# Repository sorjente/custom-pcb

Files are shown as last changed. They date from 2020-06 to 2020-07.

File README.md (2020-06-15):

# Custom STM32L4 PCB

## What?

This is an attempt to build a minimal, custom PCB featuring an STM32L4 MCU, using (ideally only) open source tools.
It will hopefully serve as a stepping stone to build more complex embedded systems.

## Why?

Because learning is fun.

## Who?

[@ayoubsabri](https://ayoubsabri.github.io/) & [@kokkonisd](https://kokkonisd.github.io/).

---

## Setting up this project

To set up this project, you can start by cloning it:

```
$ git clone https://github.com/kokkonisd/custom-pcb
```

You then need to pull `libopencm3`. You can do this by running `make` in `hello_opencm3/`, or do it manually:

```
$ git submodule init
$ git submodule update
$ cd hello_opencm3/libopencm3/ && make
```

You only need to do this once.

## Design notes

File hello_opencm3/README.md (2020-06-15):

# hello_opencm3

This is a simple blinky program whose aim is to test out minimal opencm3 code as well as a custom linker script/startup
program pair.

## Linker script (linker_stm32l452.ld)

This is the script that's fed to the linker and that maps code and data sections to the FLASH and RAM memories on the
MCU. There are some sections we need to account for:

1. `.text`: this entire area goes into the FLASH memory, and can only be read or executed.
    1. `.isr_vector`: the vector table which is essential to the MCU's startup. It's defined in the startup file, and
       its spec can be found on the [STM32L4 Reference Manual][1].
        We need to wrap it with `KEEP()` because it's not explicitly referenced anywhere else in the program, but it
        must be kept and stored at the start of the FLASH memory.
    2. `.text`: the program instructions for our firmware.
    3. `.rodata`: constants of our firmware (if any).
2. `.data`: the non-constant global variables of our firmware, which need to be stored in the FLASH memory but also
            need to be copied to the RAM during reset (see the [startup file](#startup-file-startup_stm32l452c))
3. `.bss`: the zero-initialized global variables of our firmware, which need to be stored in RAM (their values don't
           need to be "remembered" by the FLASH).

## Startup file (startup_stm32l452.c)

This file contains the vector table for the interrupts, as well as the definition of the `Default_Handler` (which just
hangs in case it's called) and the `Reset_Handler`.

The `Reset_Handler` does 3 things:

1. Copies the `.data` section from the FLASH to the RAM
2. Initializes the `.bss` section in RAM to `0`
3. Calls `main()`

This function is called at each reset, as its name implies, and it's essential in order for the firmware to work as
intended.

## Blinky program (src/main.c)

The main firmware of this example is just a simple blinky program, whose aim is to toggle a LED on and off at a certain
frequency. In the NUCLEO-L452RE-P board used for this example, the LED we want to toggle is found on the pin `PB13`.

Before toggling the LED, the clock (and also the FLASH memory) need to be configured. The aim is to have the clock run
at its maximum frequency (80 MHz), so as per the documentation ([RM0394, section 3.3.3][2]) the FLASH's wait states need to be set at 4. Since we're configuring the
FLASH, we can also enable prefetch and instruction/data cache, in order to get the maximum performance.

Concerning the clock, the easiest solution to achieve maximum speed is to use the internal oscillator (HSI), which runs
at 16 MHz. As explained in the documentation ([DS11912, section 3.11, fig. 4][3]), we need to use the main PLL in order to ramp up the speed to 80 MHz. This PLL produces a main output
clock whose frequency is given by the following formula:

```
PLLCLK = PLL_in / M * N / R
```

`PLL_in` is the input fed to the PLL (HSI in our case). Since `R` needs to be equal to at least 2 (the configurations
to choose from are 2, 4, 6 and 8) we need `16 / M * N = 160`. If we set `M = 4` and `N = 40`, this condition is
satisfied, and thus a 80 MHz clock is produced.

It should be noted that the PLL has two more outputs, one for powering USB, RNG and SDMMC, and one for powering SAI. 
Since we are not using these peripherals, we can deactivate these clocks by setting their dividers (equivalents of `R`
in the case of `PLLCLK`) to `0`. Finally, we need to enable the PLL and tell SysClk to use it as its source.

Once we enable clock feed to the port of the LED pin (`GPIOB`) and configure it in output mode, we can toggle the pin
to turn on/off the LED. A simple empty for loop is added to delay each toggle for the LED blinking to be visible.

<!-- Links -->
[1]: https://www.st.com/resource/en/reference_manual/dm00151940-stm32l41xxx42xxx43xxx44xxx45xxx46xxx-advanced-armbased-32bit-mcus-stmicroelectronics.pdf
[2]: https://www.st.com/content/ccc/resource/technical/document/reference_manual/group0/b0/ac/3e/8f/6d/21/47/af/DM00151940/files/DM00151940.pdf/jcr:content/translations/e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
[3]: https://www.st.com/resource/en/datasheet/stm32l452re.pdf

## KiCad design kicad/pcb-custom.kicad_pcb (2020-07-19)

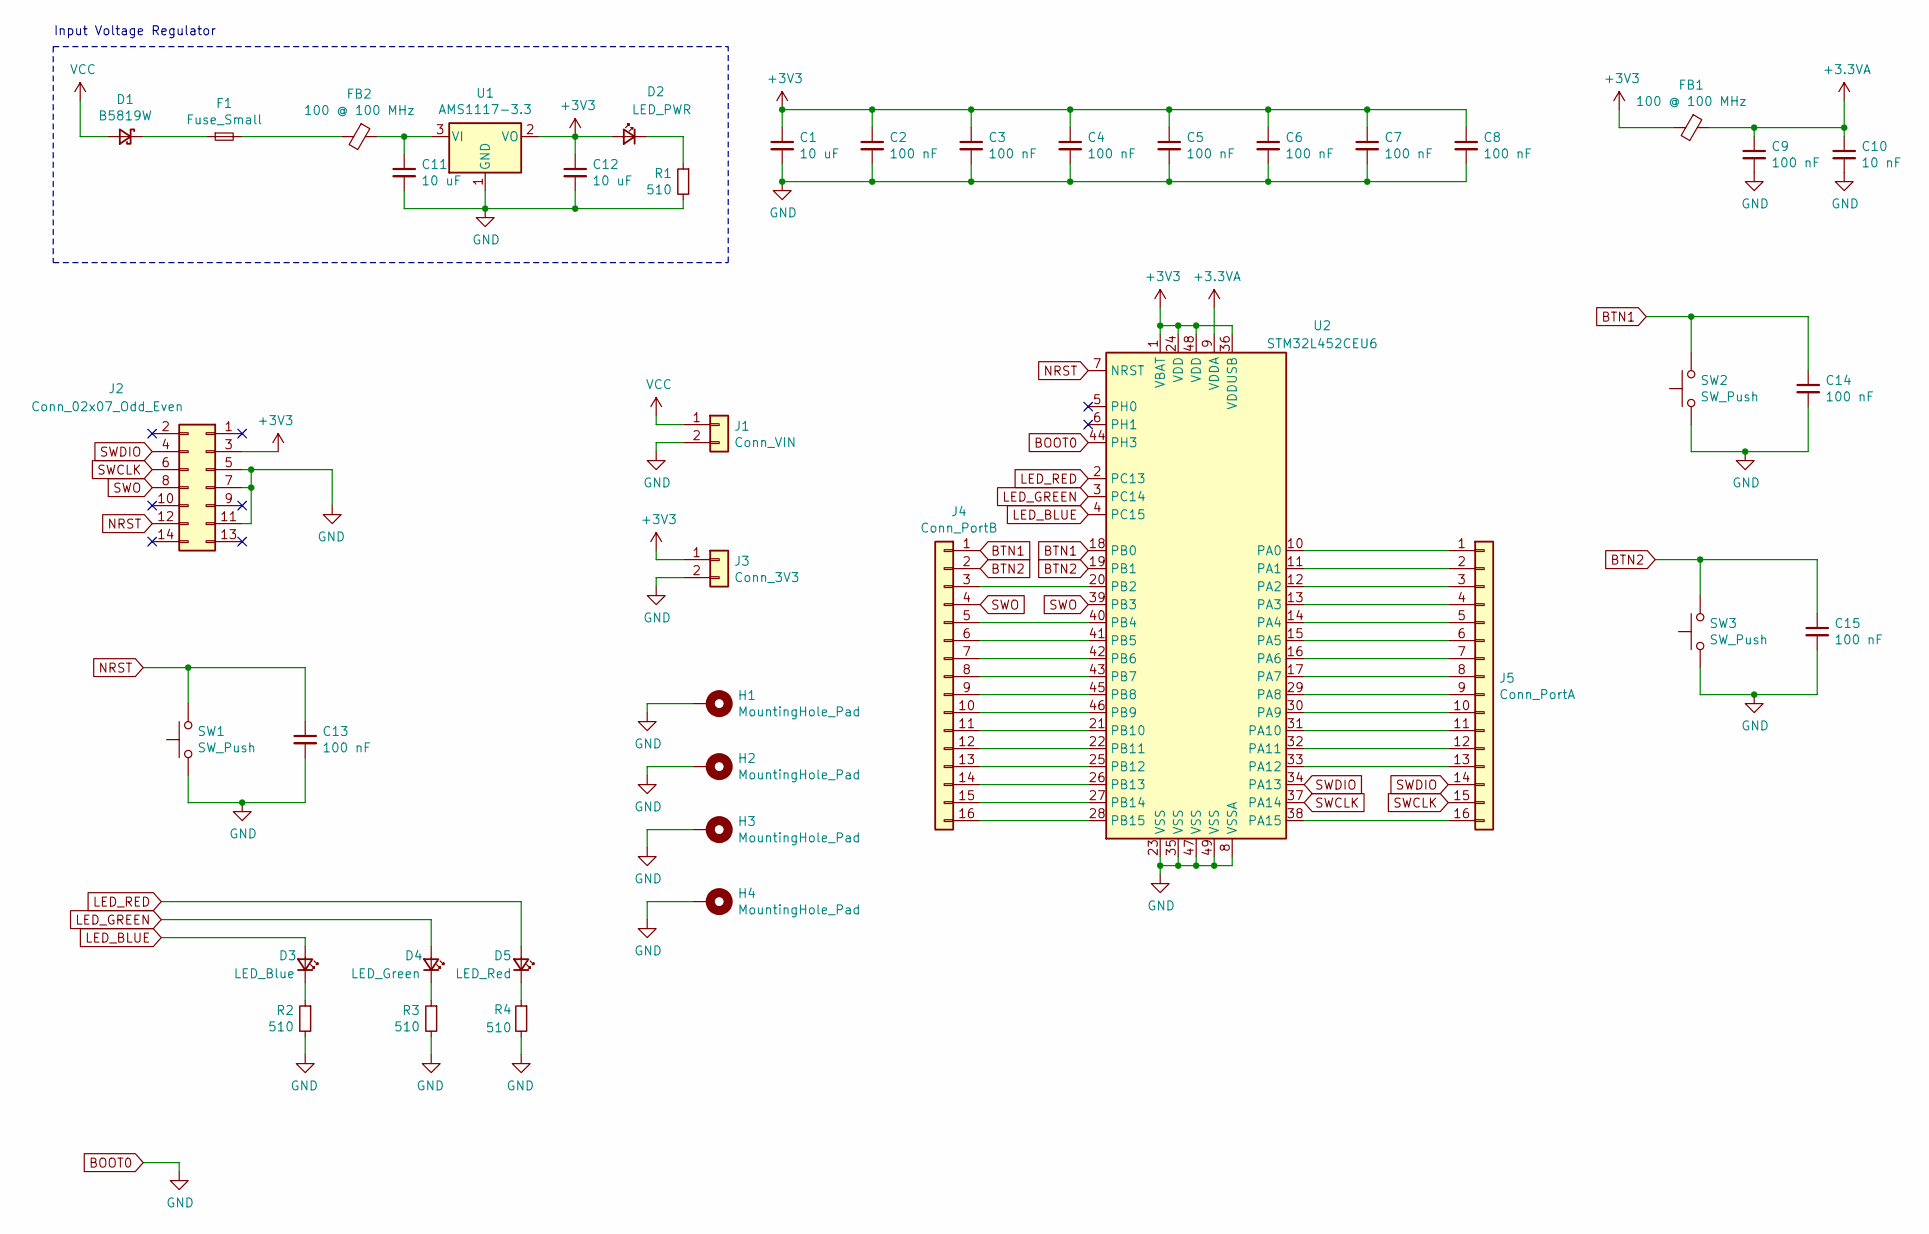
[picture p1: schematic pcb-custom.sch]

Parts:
C1, C11, C12: 10 uF; C_0805_2012Metric
C2, C3, C4, C5, C6, C7, C8, C9, C13, C14, C15: 100 nF; C_0402_1005Metric
C10: 10 nF; C_0402_1005Metric
D1: B5819W; D_SOD-123
D2: LED_PWR; LED_0603_1608Metric
D3: LED_Blue; LED_0603_1608Metric
D4: LED_Green; LED_0603_1608Metric
D5: LED_Red; LED_0603_1608Metric
F1: Fuse_Small; Fuse_0603_1608Metric
FB1, FB2: 100 @ 100 MHz; L_0805_2012Metric
H1, H2, H3, H4: MountingHole_Pad; MountingHole_4.3mm_M4_Pad_Via
J1: Conn_VIN; PinHeader_1x02_P2.54mm_Vertical
J2: Conn_02x07_Odd_Even; PinHeader_2x07_P1.27mm_Vertical
J3: Conn_3V3; PinHeader_1x02_P2.54mm_Vertical
J4: Conn_PortB; PinHeader_1x16_P2.54mm_Vertical
J5: Conn_PortA; PinHeader_1x16_P2.54mm_Vertical
R1, R2, R3, R4: 510; R_0603_1608Metric
SW1, SW2, SW3: SW_Push; SW_SPST_EVQP0
U1: AMS1117-3.3; SOT-223-3_TabPin2
U2: STM32L452CEU6; QFN-48-1EP_7x7mm_P0.5mm_EP5.6x5.6mm

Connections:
+3.3VA: C9.1, C10.1, FB1.1, U2.9 (VDDA)
+3V3: C1.1, C2.1, C3.1, C4.1, C5.1, C6.1, C7.1, C8.1, C12.1, D2.2 (A), FB1.2, J2.3, J3.1, U1.2 (VO), U2.1 (VBAT), U2.24 (VDD), U2.36 (VDDUSB), U2.48 (VDD)
BOOT0: C1.2, C2.2, C3.2, C4.2, C5.2, C6.2, C7.2, C8.2, C9.2, C10.2, C11.2, C12.2, C13.2, C14.2, C15.2, H1.1, H2.1, H3.1, H4.1, J1.2, J2.5, J2.7, J2.11, J3.2, R1.2, R2.2, R3.2, R4.2, SW1.1, SW2.1, SW3.1, U1.1 (GND), U2.8 (VSSA), U2.23 (VSS), U2.35 (VSS), U2.44 (PH3), U2.47 (VSS), U2.49 (VSS)
BTN1: C14.1, J4.1, SW2.2, U2.18 (PB0)
BTN2: C15.1, J4.2, SW3.2, U2.19 (PB1)
LED_BLUE: D3.2 (A), U2.4 (PC15)
LED_GREEN: D4.2 (A), U2.3 (PC14)
LED_RED: D5.2 (A), U2.2 (PC13)
NRST: C13.1, J2.12, SW1.2, U2.7 (NRST)
unnamed: C11.1, FB2.1, U1.3 (VI)
unnamed: D1.1 (K), F1.1
unnamed: D2.1 (K), R1.1
unnamed: D3.1 (K), R2.1
unnamed: D4.1 (K), R3.1
unnamed: D5.1 (K), R4.1
unnamed: F1.2, FB2.2
unnamed: J4.3, U2.20 (PB2)
unnamed: J4.5, U2.40 (PB4)
unnamed: J4.6, U2.41 (PB5)
unnamed: J4.7, U2.42 (PB6)
unnamed: J4.8, U2.43 (PB7)
unnamed: J4.9, U2.45 (PB8)
unnamed: J4.10, U2.46 (PB9)
unnamed: J4.11, U2.21 (PB10)
unnamed: J4.12, U2.22 (PB11)
unnamed: J4.13, U2.25 (PB12)
unnamed: J4.14, U2.26 (PB13)
unnamed: J4.15, U2.27 (PB14)
unnamed: J4.16, U2.28 (PB15)
unnamed: J5.1, U2.10 (PA0)
unnamed: J5.2, U2.11 (PA1)
unnamed: J5.3, U2.12 (PA2)
unnamed: J5.4, U2.13 (PA3)
unnamed: J5.5, U2.14 (PA4)
unnamed: J5.6, U2.15 (PA5)
unnamed: J5.7, U2.16 (PA6)
unnamed: J5.8, U2.17 (PA7)
unnamed: J5.9, U2.29 (PA8)
unnamed: J5.10, U2.30 (PA9)
unnamed: J5.11, U2.31 (PA10)
unnamed: J5.12, U2.32 (PA11)
unnamed: J5.13, U2.33 (PA12)
unnamed: J5.16, U2.38 (PA15)
SWCLK: J2.6, J5.15, U2.37 (PA14)
SWDIO: J2.4, J5.14, U2.34 (PA13)
SWO: J2.8, J4.4, U2.39 (PB3)
VCC: D1.2 (A), J1.1

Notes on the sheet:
Input Voltage Regulator

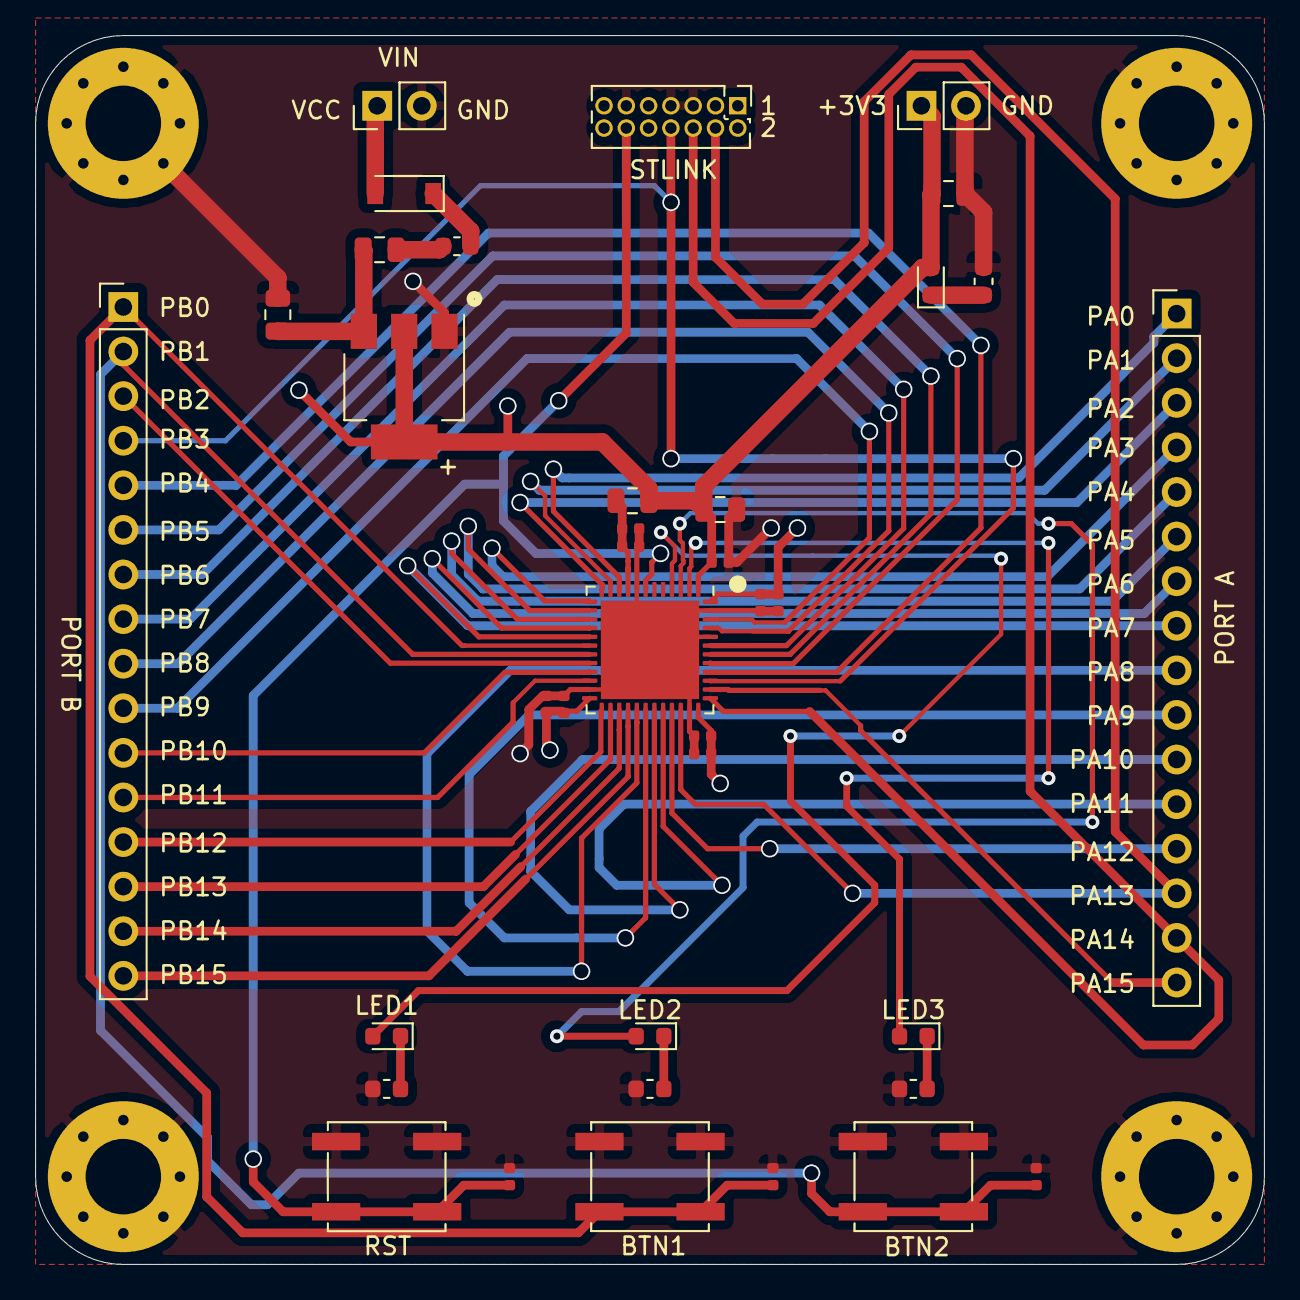
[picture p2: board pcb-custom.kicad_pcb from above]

Board: 4 copper layers, 70.0 x 70.0 mm, 41 parts (0 on the bottom side), 47 nets.

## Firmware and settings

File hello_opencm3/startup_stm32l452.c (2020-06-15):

#include <stdint.h>

extern uint32_t _etext;
extern uint32_t _sdata;
extern uint32_t _edata;
extern uint32_t _sbss;
extern uint32_t _ebss;

#define START_RAM   0x20000000U
#define SIZE_RAM    (160 * 1024) // 160K

#define START_STACK ((START_RAM) + (SIZE_RAM))

int main(void);

void Reset_Handler(void);
void Default_Handler(void);

void NMI_Handler(void)                  __attribute__((weak, alias("Default_Handler")));
void HardFault_Handler(void)            __attribute__((weak, alias("Default_Handler")));
void MemManage_Handler(void)            __attribute__((weak, alias("Default_Handler")));
void BusFault_Handler(void)             __attribute__((weak, alias("Default_Handler")));
void UsageFault_Handler(void)           __attribute__((weak, alias("Default_Handler")));
void SVCall_Handler(void)               __attribute__((weak, alias("Default_Handler")));
void Debug_Handler(void)                __attribute__((weak, alias("Default_Handler")));
void PendSV_Handler(void)               __attribute__((weak, alias("Default_Handler")));
void SysTick_Handler(void)              __attribute__((weak, alias("Default_Handler")));

void WWDG_Handler(void)                 __attribute__((weak, alias("Default_Handler")));
void PVD_PVM_Handler(void)              __attribute__((weak, alias("Default_Handler")));
void RTC_TAMP_STAMP_Handler(void)       __attribute__((weak, alias("Default_Handler")));
void RTC_WKUP_Handler(void)             __attribute__((weak, alias("Default_Handler")));
void FLASH_Handler(void)                __attribute__((weak, alias("Default_Handler")));
void RCC_Handler(void)                  __attribute__((weak, alias("Default_Handler")));
void EXTI0_Handler(void)                __attribute__((weak, alias("Default_Handler")));
void EXTI1_Handler(void)                __attribute__((weak, alias("Default_Handler")));
void EXTI2_Handler(void)                __attribute__((weak, alias("Default_Handler")));
void EXTI3_Handler(void)                __attribute__((weak, alias("Default_Handler")));
void EXTI4_Handler(void)                __attribute__((weak, alias("Default_Handler")));
void DMA1_CH1_Handler(void)             __attribute__((weak, alias("Default_Handler")));
void DMA1_CH2_Handler(void)             __attribute__((weak, alias("Default_Handler")));
void DMA1_CH3_Handler(void)             __attribute__((weak, alias("Default_Handler")));
void DMA1_CH4_Handler(void)             __attribute__((weak, alias("Default_Handler")));
void DMA1_CH5_Handler(void)             __attribute__((weak, alias("Default_Handler")));
void DMA1_CH6_Handler(void)             __attribute__((weak, alias("Default_Handler")));
void DMA1_CH7_Handler(void)             __attribute__((weak, alias("Default_Handler")));
void ADC1_2_Handler(void)               __attribute__((weak, alias("Default_Handler")));
void CAN1_TX_Handler(void)              __attribute__((weak, alias("Default_Handler")));
void CAN1_RX_0_Handler(void)            __attribute__((weak, alias("Default_Handler")));
void CAN1_RX_1_Handler(void)            __attribute__((weak, alias("Default_Handler")));
void CAN1_SCE_Handler(void)             __attribute__((weak, alias("Default_Handler")));
void EXTI9_5_Handler(void)              __attribute__((weak, alias("Default_Handler")));
void TIM1_BRK_Handler(void)             __attribute__((weak, alias("Default_Handler")));
void TIM1_UP_Handler(void)              __attribute__((weak, alias("Default_Handler")));
void TIM1_TRG_COM_Handler(void)         __attribute__((weak, alias("Default_Handler")));
void TIM1_CC_Handler(void)              __attribute__((weak, alias("Default_Handler")));
void TIM2_Handler(void)                 __attribute__((weak, alias("Default_Handler")));
void TIM3_Handler(void)                 __attribute__((weak, alias("Default_Handler")));
void I2C1_EV_Handler(void)              __attribute__((weak, alias("Default_Handler")));
void I2C1_ER_Handler(void)              __attribute__((weak, alias("Default_Handler")));
void I2C2_EV_Handler(void)              __attribute__((weak, alias("Default_Handler")));
void I2C2_ER_Handler(void)              __attribute__((weak, alias("Default_Handler")));
void SPI1_Handler(void)                 __attribute__((weak, alias("Default_Handler")));
void SPI2_Handler(void)                 __attribute__((weak, alias("Default_Handler")));
void USART1_Handler(void)               __attribute__((weak, alias("Default_Handler")));
void USART2_Handler(void)               __attribute__((weak, alias("Default_Handler")));
void USART3_Handler(void)               __attribute__((weak, alias("Default_Handler")));
void EXTI15_10_Handler(void)            __attribute__((weak, alias("Default_Handler")));
void RTC_ALARM_Handler(void)            __attribute__((weak, alias("Default_Handler")));
void SDMMC1_Handler(void)               __attribute__((weak, alias("Default_Handler")));
void SPI3_Handler(void)                 __attribute__((weak, alias("Default_Handler")));
void UART4_Handler(void)                __attribute__((weak, alias("Default_Handler")));
void TIM6_DACUNDER_Handler(void)        __attribute__((weak, alias("Default_Handler")));
void DMA2_CH1_Handler(void)             __attribute__((weak, alias("Default_Handler")));
void DMA2_CH2_Handler(void)             __attribute__((weak, alias("Default_Handler")));
void DMA2_CH3_Handler(void)             __attribute__((weak, alias("Default_Handler")));
void DMA2_CH4_Handler(void)             __attribute__((weak, alias("Default_Handler")));
void DMA2_CH5_Handler(void)             __attribute__((weak, alias("Default_Handler")));
void DFSDM1_FLT0_Handler(void)          __attribute__((weak, alias("Default_Handler")));
void DFSDM1_FLT1_Handler(void)          __attribute__((weak, alias("Default_Handler")));
void COMP_Handler(void)                 __attribute__((weak, alias("Default_Handler")));
void LPTIM1_Handler(void)               __attribute__((weak, alias("Default_Handler")));
void LPTIM2_Handler(void)               __attribute__((weak, alias("Default_Handler")));
void USB_FS_Handler(void)               __attribute__((weak, alias("Default_Handler")));
void DMA2_CH6_Handler(void)             __attribute__((weak, alias("Default_Handler")));
void DMA2_CH7_Handler(void)             __attribute__((weak, alias("Default_Handler")));
void LPUART1_Handler(void)              __attribute__((weak, alias("Default_Handler")));
void QUADSPI_Handler(void)              __attribute__((weak, alias("Default_Handler")));
void I2C3_EV_Handler(void)              __attribute__((weak, alias("Default_Handler")));
void I2C3_ER_Handler(void)              __attribute__((weak, alias("Default_Handler")));
void SAI1_Handler(void)                 __attribute__((weak, alias("Default_Handler")));
void TSC_Handler(void)                  __attribute__((weak, alias("Default_Handler")));
void RNG_Handler(void)                  __attribute__((weak, alias("Default_Handler")));
void FPU_Handler(void)                  __attribute__((weak, alias("Default_Handler")));
void CRS_Handler(void)                  __attribute__((weak, alias("Default_Handler")));
void I2C4_EV_Handler(void)              __attribute__((weak, alias("Default_Handler")));
void I2C4_ER_Handler(void)              __attribute__((weak, alias("Default_Handler")));

uint32_t vectorTable[] __attribute__((section(".isr_vector"))) = {
    (uint32_t)START_STACK,
    (uint32_t)Reset_Handler,
    (uint32_t)NMI_Handler,
    (uint32_t)HardFault_Handler,
    (uint32_t)MemManage_Handler,
    (uint32_t)BusFault_Handler,
    (uint32_t)UsageFault_Handler,
    0,
    (uint32_t)SVCall_Handler,
    (uint32_t)Debug_Handler,
    0,
    (uint32_t)PendSV_Handler,
    (uint32_t)SysTick_Handler,
    (uint32_t)WWDG_Handler,
    (uint32_t)PVD_PVM_Handler,
    (uint32_t)RTC_TAMP_STAMP_Handler,
    (uint32_t)RTC_WKUP_Handler,
    (uint32_t)FLASH_Handler,
    (uint32_t)RCC_Handler,
    (uint32_t)EXTI0_Handler,
    (uint32_t)EXTI1_Handler,
    (uint32_t)EXTI2_Handler,
    (uint32_t)EXTI3_Handler,
    (uint32_t)EXTI4_Handler,
    (uint32_t)DMA1_CH1_Handler,
    (uint32_t)DMA1_CH2_Handler,
    (uint32_t)DMA1_CH3_Handler,
    (uint32_t)DMA1_CH4_Handler,
    (uint32_t)DMA1_CH5_Handler,
    (uint32_t)DMA1_CH6_Handler,
    (uint32_t)DMA1_CH7_Handler,
    (uint32_t)ADC1_2_Handler,
    (uint32_t)CAN1_TX_Handler,
    (uint32_t)CAN1_RX_0_Handler,
    (uint32_t)CAN1_RX_1_Handler,
    (uint32_t)CAN1_SCE_Handler,
    (uint32_t)EXTI9_5_Handler,
    (uint32_t)TIM1_BRK_Handler,
    (uint32_t)TIM1_UP_Handler,
    (uint32_t)TIM1_TRG_COM_Handler,
    (uint32_t)TIM1_CC_Handler,
    (uint32_t)TIM2_Handler,
    (uint32_t)TIM3_Handler,
    0,
    (uint32_t)I2C1_EV_Handler,
    (uint32_t)I2C1_ER_Handler,
    (uint32_t)I2C2_EV_Handler,
    (uint32_t)I2C2_ER_Handler,
    (uint32_t)SPI1_Handler,
    (uint32_t)SPI2_Handler,
    (uint32_t)USART1_Handler,
    (uint32_t)USART2_Handler,
    (uint32_t)USART3_Handler,
    (uint32_t)EXTI15_10_Handler,
    (uint32_t)RTC_ALARM_Handler,
    0,
    0,
    0,
    0,
    0,
    0,
    0,
    (uint32_t)SDMMC1_Handler,
    0,
    (uint32_t)SPI3_Handler,
    (uint32_t)UART4_Handler,
    0,
    (uint32_t)TIM6_DACUNDER_Handler,
    0,
    (uint32_t)DMA2_CH1_Handler,
    (uint32_t)DMA2_CH2_Handler,
    (uint32_t)DMA2_CH3_Handler,
    (uint32_t)DMA2_CH4_Handler,
    (uint32_t)DMA2_CH5_Handler,
    (uint32_t)DFSDM1_FLT0_Handler,
    (uint32_t)DFSDM1_FLT1_Handler,
    0,
    (uint32_t)COMP_Handler,
    (uint32_t)LPTIM1_Handler,
    (uint32_t)LPTIM2_Handler,
    (uint32_t)USB_FS_Handler,
    (uint32_t)DMA2_CH6_Handler,
    (uint32_t)DMA2_CH7_Handler,
    (uint32_t)LPUART1_Handler,
    (uint32_t)QUADSPI_Handler,
    (uint32_t)I2C3_EV_Handler,
    (uint32_t)I2C3_ER_Handler,
    (uint32_t)SAI1_Handler,
    0,
    0,
    (uint32_t)TSC_Handler,
    0,
    0,
    (uint32_t)RNG_Handler,
    (uint32_t)FPU_Handler,
    (uint32_t)CRS_Handler,
    (uint32_t)I2C4_EV_Handler,
    (uint32_t)I2C4_ER_Handler
};

void Default_Handler(void)
{
    while (1);
}

void Reset_Handler(void)
{
    uint32_t data_size = (uint32_t)&_edata - (uint32_t)&_sdata;
    uint32_t bss_size = (uint32_t)&_ebss - (uint32_t)&_sbss;

    uint8_t *p_data_ram     = (uint8_t*)&_sdata;
    uint8_t *p_data_flash   = (uint8_t*)&_etext;

    uint8_t *p_bss          = (uint8_t*)&_sbss;

    // Copy .data to ram
    for (uint32_t i = 0; i < data_size; i++)
    {
        p_data_ram[i] = p_data_flash[i];
    }

    // Initialize .bss to 0
    for (uint32_t i = 0; i < bss_size; i++)
    {
        p_bss[i] = 0U;
    }

    main();
}

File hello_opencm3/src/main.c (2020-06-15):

#include <stdio.h>
#include <stdint.h>
#include <libopencm3/stm32/rcc.h>
#include <libopencm3/stm32/flash.h>
#include <libopencm3/stm32/gpio.h>

#define LED_GPIO_PORT GPIOB
#define LED_GPIO_PIN  GPIO13
#define LED_RCC       RCC_GPIOB


/**
 * @brief Setups clock (80 MHz) and flash memory.
 */
static void clock_and_flash_setup (void)
{
    // Turn on High Speed Internal oscillator @ 16 MHz 
    rcc_osc_on(RCC_HSI16);
    
    // Enable prefetch to decrease instruction load/execution times
    // This needs to be done under specific clock settings, so it must be done before the clock is at 80 MHz
    flash_prefetch_enable();
    // Set flash wait states to 4, because clock will be @ 80 MHz
    // See manual RM0394/DM00151940, section 3.3.3 (page 79)
    flash_set_ws(4);
    // Enable data & instruction cache
    flash_dcache_enable();
    flash_icache_enable();

    // STM32L452 datasheet, page 36 (https://www.st.com/resource/en/datasheet/stm32l452re.pdf)
    // PLLSAI1CLK = PLL_in / M * N / P
    // PLL48M1CLK = PLL_in / M * N / Q
    // PLLCLK     = PLL_in / M * N / R
    // 
    // We are interested in PLLCLK. To get 80 MHz (the MCU's max frequency), we can supply HSI to the PLL and we have
    // to set R to at least 2. Given those two, we need to set M to 4 and N to 40 in order to get 80 MHz in the output:
    // PLLCLK = 16 MHz / 4 * 40 / 2 = 80 MHz
    // 
    // Setting P and Q to 0 probably just deactivates those clocks. PLLSAI1CLK produces a clock for the SAI peripheral,
    // while PLL48M1CLK produces a clock for USB. Since we are not using those, we can deactivate the clocks.
    rcc_set_main_pll(RCC_PLLCFGR_PLLSRC_HSI16, 4, 40, 0, 0, RCC_PLLCFGR_PLLR_DIV2);
    // Turn PLL on
    rcc_osc_on(RCC_PLL);

    // Enable clock for the LED GPIO Port
    rcc_periph_clock_enable(LED_RCC);

    // Set SysClk source to be the PLL we just configured
    rcc_set_sysclk_source(RCC_CFGR_SW_PLL);
    rcc_wait_for_sysclk_status(RCC_PLL);
}


int main (void)
{
    // Setup clock and flash
    clock_and_flash_setup();

    // Set LED as output
    gpio_mode_setup(LED_GPIO_PORT, GPIO_MODE_OUTPUT, GPIO_PUPD_NONE, LED_GPIO_PIN);

    // Toggle led
    while (1) {
        gpio_toggle(LED_GPIO_PORT, LED_GPIO_PIN);
        for (int i = 0; i < 5000000; i++);
    }

    return 0;
}

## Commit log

2020-06-14 Write startup and linker scripts (broken)
    [startup_stm32l452.c]
2020-07-05 Add kicad project files
    [pcb-custom.kicad_pcb, pcb-custom.sch]
2020-07-05 Start routing
    [pcb-custom.sch]
2020-07-19 Complete routing
    [pcb-custom.kicad_pcb]
